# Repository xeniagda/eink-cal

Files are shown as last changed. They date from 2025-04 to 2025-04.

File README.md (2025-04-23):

# eink-cal

e-ink calendar based on the *esp32-wroom32* and the waveshare *7.3inch e-Paper HAT (F)*

## file structure

* `./bridge_pcb/`: kicad project for the PCB
* `./eink_bridge/`: esp32-idf project for the WiFi-controller for the display
* `./case.FCStd`: freecad project modelling the 3d-printable chassis for the project
* `./cal_render/`: python code to render the calendar

## needed files

the file `./eink_bridge/main/wifi_creds.h` should be filled in with the following

```c

#ifndef wifi_creds_h_INCLUDED
#define wifi_creds_h_INCLUDED

#define WIFI_SSID "WIFI network SSID here"
#define WIFI_PASSWORD "WIFI network password"
static const char *REMOTE_IP = "IP of computer running cal_render";
static const int REMOTE_PORT = port of the above;

#endif // wifi_creds_h_INCLUDED
```

the file `./cal_render/secrets.toml` contains all calendars to be shown

```toml
[[calendar]]
# hemma
is_caldav = true # true for caldav, false for ical/http
username = "caldav username"
password = "caldav password"
url = "caldav URL"
color1 = "primary color" # one of BLACK, WHITE, BLUE, ORANGE, GREEN, RED, PURPLE
color2 = "secondary color"
```

## credits

font packaged and used is [ultlf](https://github.com/ultlang/ultlf) by emma ultlang. all parts of `./cal_render/ultlf` are re-released under the same SIL open font license.

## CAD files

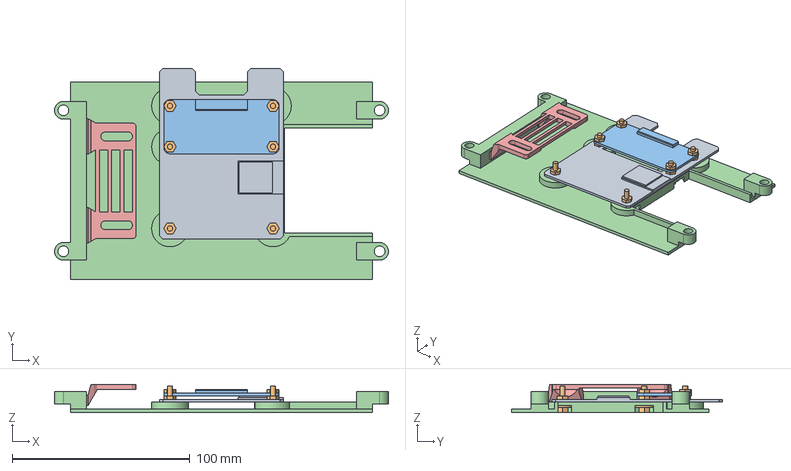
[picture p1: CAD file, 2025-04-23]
case.FCStd
188.0 x 118.7 x 16.0 mm
Bridge
Screws
Daughter001
Inner
Hanger

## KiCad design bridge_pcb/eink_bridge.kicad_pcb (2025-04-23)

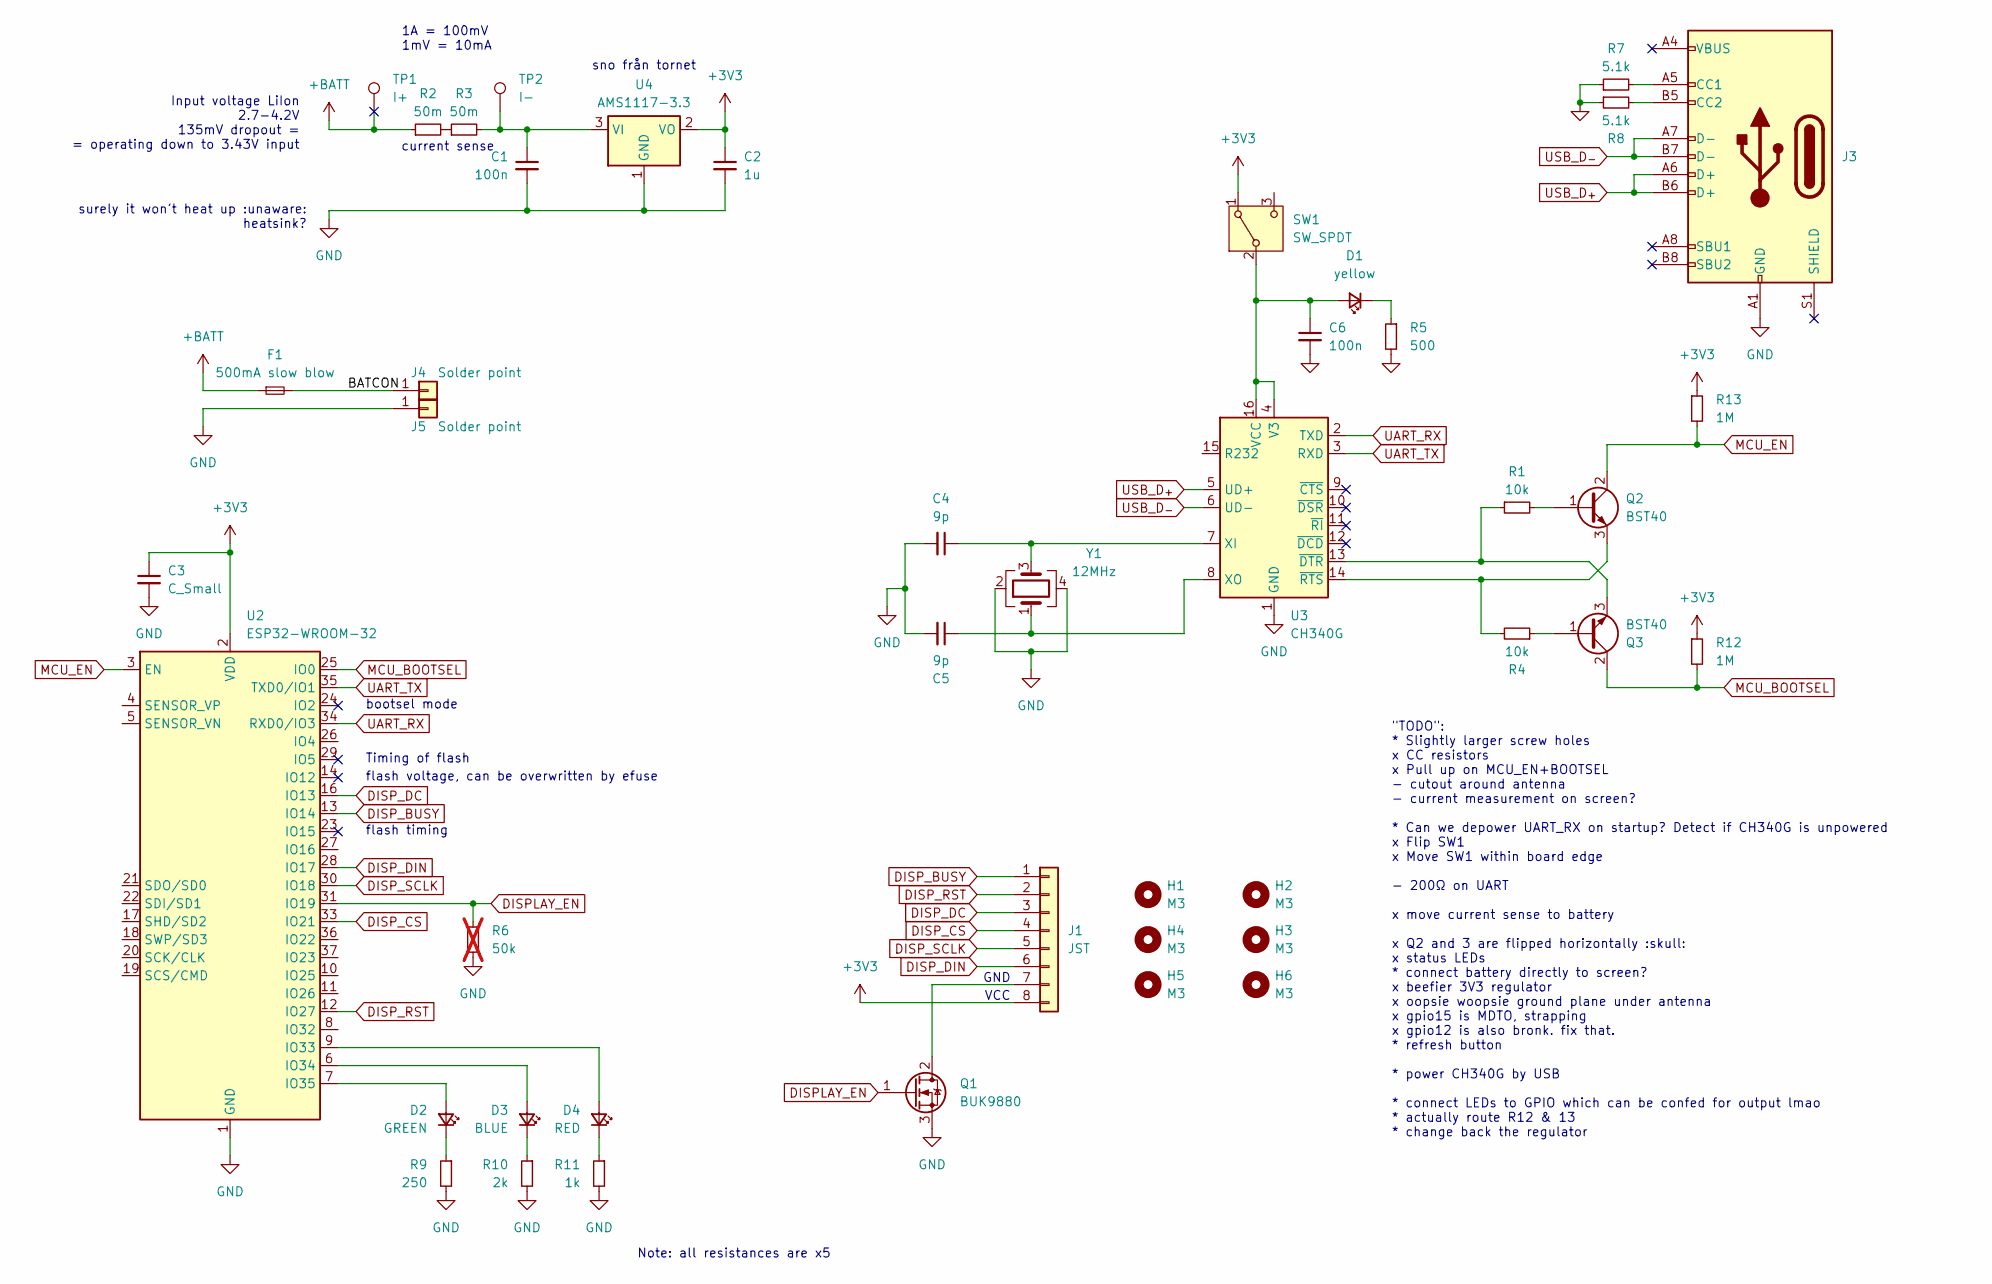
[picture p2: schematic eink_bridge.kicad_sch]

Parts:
C1, C6: 100n; C_0603_1608Metric_Pad1.08x0.95mm_HandSolder
C2: 1u; C_0603_1608Metric_Pad1.08x0.95mm_HandSolder
C3: C_Small; C_0603_1608Metric_Pad1.08x0.95mm_HandSolder
C4, C5: 9p; C_0603_1608Metric_Pad1.08x0.95mm_HandSolder
D1: yellow; D_0603_1608Metric_Pad1.05x0.95mm_HandSolder
D2: GREEN; LED_0603_1608Metric_Pad1.05x0.95mm_HandSolder
D3: BLUE; LED_0603_1608Metric_Pad1.05x0.95mm_HandSolder
D4: RED; LED_0603_1608Metric_Pad1.05x0.95mm_HandSolder
F1: 500mA slow blow; Fuseholder_Cylinder-5x20mm_Schurter_OGN-SMD_Horizontal_Open
H1, H2, H3, H4, H5, H6: M3; MountingHole_3.2mm_M3
J1: JST; JST_PH_B8B-PH-SM4-TB_1x08-1MP_P2.00mm_Vertical
J3: USB_C_Receptacle_USB2.0_16P; USB_C_Receptacle_GCT_USB4110
J4, J5: Solder point; TestPoint_Keystone_5019_Minature
Q1: BUK9880; SOT-223-3_TabPin2
Q2, Q3: BST40; SOT-89-3_Handsoldering
R1, R4: 10k; R_0603_1608Metric_Pad0.98x0.95mm_HandSolder
R2, R3: 50m; R_0805_2012Metric_Pad1.20x1.40mm_HandSolder
R5: 500; R_0603_1608Metric_Pad0.98x0.95mm_HandSolder
R6: 50k; R_0603_1608Metric_Pad0.98x0.95mm_HandSolder; not fitted
R7, R8: 5.1k; R_0603_1608Metric_Pad0.98x0.95mm_HandSolder
R9: 250; R_0603_1608Metric_Pad0.98x0.95mm_HandSolder
R10: 2k; R_0603_1608Metric_Pad0.98x0.95mm_HandSolder
R11: 1k; R_0603_1608Metric_Pad0.98x0.95mm_HandSolder
R12, R13: 1M
SW1: SW_SPDT; PinHeader_1x03_P2.54mm_Horizontal
TP1: I+; TestPoint_Bridge_Pitch3.81mm_Drill1.3mm
TP2: I-; TestPoint_Bridge_Pitch3.81mm_Drill1.3mm
U2: ESP32-WROOM-32
U3: CH340G; SOIC-16_3.9x9.9mm_P1.27mm
U4: AMS1117-3.3; SOT-223-3_TabPin2
Y1: 12MHz; Crystal_SMD_3225-4Pin_3.2x2.5mm_HandSoldering

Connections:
+3V3: C2.1, C3.1, J1.8, R12.1, R13.1, SW1.1 (A), U2.2 (VDD), U4.2 (VO)
+BATT: F1.1, R2.1, TP1.1
/BATCON: F1.2, J4.1
DISPLAY_EN: Q1.1 (G), R6.1, U2.31 (IO19)
DISP_BUSY: J1.1, U2.13 (IO14)
DISP_CS: J1.4, U2.33 (IO21)
DISP_DC: J1.3, U2.16 (IO13)
DISP_DIN: J1.6, U2.28 (IO17)
DISP_RST: J1.2, U2.12 (IO27)
DISP_SCLK: J1.5, U2.30 (IO18)
GND: C1.2, C2.2, C3.2, C4.2, C5.2, C6.2, J3.A1 (GND), J3.A12 (GND), J3.B1 (GND), J3.B12 (GND), J5.1, Q1.3 (S), R5.2, R6.2, R7.1, R8.1, R9.2, R10.2, R11.2, U2.1 (GND), U2.15 (GND), U2.38 (GND), U2.39 (GND), U3.1 (GND), U4.1 (GND), Y1.2, Y1.4
MCU_BOOTSEL: Q3.2 (C), R12.2, U2.25 (IO0)
MCU_EN: Q2.2 (C), R13.2, U2.3 (EN)
unnamed: C6.1, D1.2 (A), SW1.2 (B), U3.4 (V3), U3.16 (VCC)
unnamed: D1.1 (K), R5.1
unnamed: D2.2 (A), U2.7 (IO35)
unnamed: D2.1 (K), R9.1
unnamed: D3.2 (A), U2.6 (IO34)
unnamed: D3.1 (K), R10.1
unnamed: D4.2 (A), U2.9 (IO33)
unnamed: D4.1 (K), R11.1
unnamed: J1.7, Q1.2 (D)
unnamed: J3.A5 (CC1), R7.2
unnamed: J3.B5 (CC2), R8.2
unnamed: Q2.1 (B), R1.2
unnamed: Q2.3 (E), R4.2, U3.14 (~RTS)
unnamed: Q3.1 (B), R4.1
unnamed: Q3.3 (E), R1.1, U3.13 (~DTR)
unnamed: R2.2, R3.1
unnamed: C4.1, U3.7 (XI), Y1.3
unnamed: C5.1, U3.8 (XO), Y1.1
unnamed: C1.1, R3.2, TP2.1, U4.3 (VI)
UART_RX: U2.34 (RXD0/IO3), U3.2 (TXD)
UART_TX: U2.35 (TXD0/IO1), U3.3 (RXD)
USB_D_{+}: J3.A6 (D+), J3.B6 (D+), U3.5 (UD+)
USB_D_{-}: J3.A7 (D-), J3.B7 (D-), U3.6 (UD-)

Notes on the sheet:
GND
1A = 100mV 1mV = 10mA
VCC
current sense
flash timing
surely it won't heat up :unaware: heatsink?
sno från tornet
bootsel mode
"TODO": * Slightly larger screw holes x CC resistors x Pull up on MCU_EN+BOOTSEL - cutout around antenna - current measurement on screen? * Can we depower UART_RX on startup? Detect if CH340G is unpowered x Flip SW1 x Move SW1 within board edge - 200Ω on UART x move current sense to battery x Q2 an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
Note: all resistances are x5
flash voltage, can be overwritten by efuse
Timing of flash
Input voltage LiIon 2.7-4.2V 135mV dropout = = operating down to 3.43V input

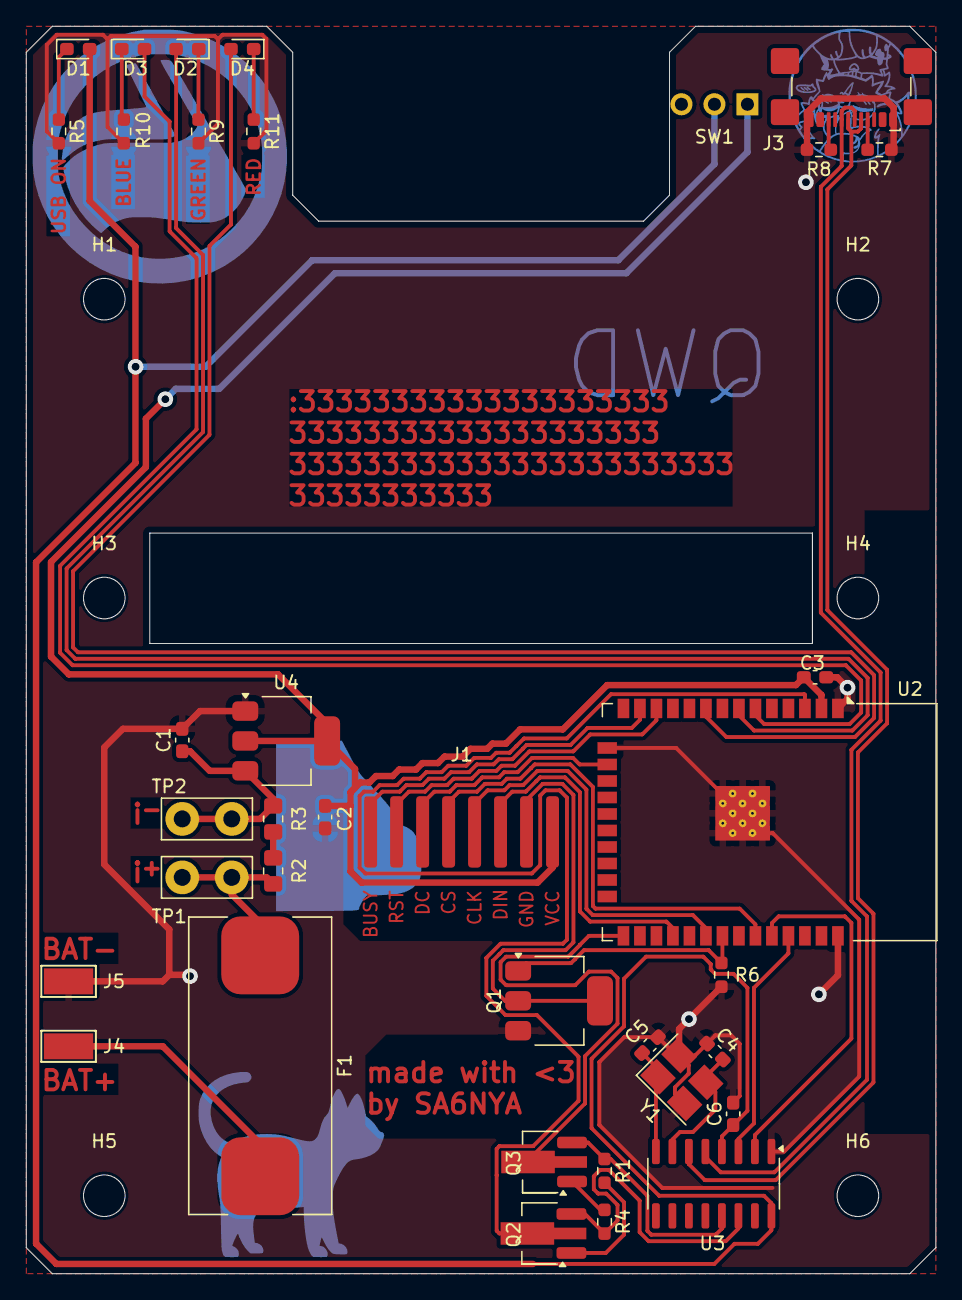
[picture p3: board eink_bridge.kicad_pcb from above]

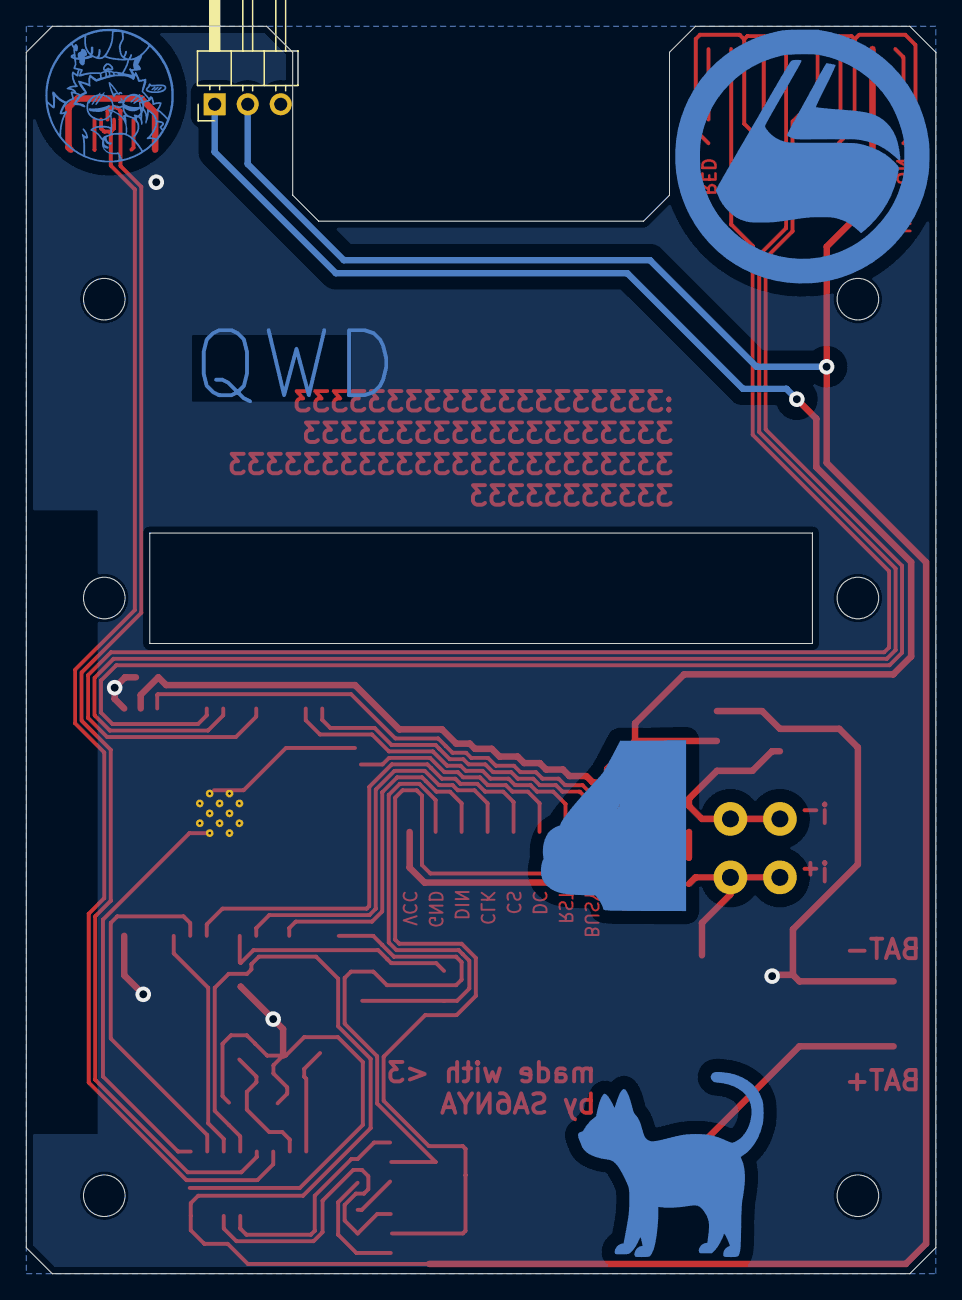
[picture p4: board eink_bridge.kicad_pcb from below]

Board: 2 copper layers, 70.0 x 96.0 mm, 44 parts (3 on the bottom side), 36 nets.

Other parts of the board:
Ref**: Val**; t42
Ref**#2: Val**; furry-antifa-20mm

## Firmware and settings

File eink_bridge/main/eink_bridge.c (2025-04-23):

#include <stdio.h>
#include <math.h>

#include "esp_err.h"
#include "esp_log.h"
#include "esp_event.h"
#include "esp_random.h"
#include "esp_sleep.h"
#include "driver/gpio.h"

#include "esp_netif.h"
#include "freertos/idf_additions.h"
#include "lwip/inet.h"
#include "nvs_flash.h"

#include "lwip/sockets.h"

#include "led.h"
#include "portmacro.h"
#include "stdint.h"
#include "wifi.h"
#include "wifi_creds.h"
#include "eink_display.h"

static const char *TAG = "eink_bridge";

static const uint64_t SLEEP_TIME_US = 4 * 60 * 60 * 1000000ull; // every 4 hours
static const uint64_t RECONNECT_ATTEMPTS = 5;
static const uint64_t RECONNECT_TIME_MS = 3000;

esp_err_t send_exact(int fd, char *buf, size_t nbytes) {
    while (nbytes > 0) {
        int written = send(fd, buf, nbytes, 0);
        if (written < 0) {
            ESP_LOGE(TAG, "Failed to send: %d", errno);
            return ESP_FAIL;
        }
        nbytes -= written;
        buf += written;
    }
    return ESP_OK;
}

esp_err_t recv_exact(int fd, char *buf, size_t nbytes) {
    while (nbytes > 0) {
        ESP_LOGD("recv_exact", "recving...");
        int recvd = recv(fd, buf, nbytes, 0);
        ESP_LOGD("recv_exact", "got %d bytes", recvd);
        if (recvd < 0) {
            ESP_LOGE(TAG, "Failed to recv: %d", errno);
            return ESP_FAIL;
        }
        if (recvd == 0) {
            ESP_LOGE(TAG, "Connection closed");
            return ESP_FAIL;
        }
        nbytes -= recvd;
        buf += recvd;
    }
    return ESP_OK;
}

float gauss() {
    #define clt_count 10
    float n = 0.;
    for (int i = 0; i < clt_count; i++) {
        // variance 1/12
        float ni = ((float) rand() / (float)RAND_MAX) - 0.5;
        n += ni;
    }
    // n has total variance clt_count/12
    return n / sqrtf(clt_count/12.0);

}

esp_err_t display_fill_pattern() {
    ESP_LOGI(TAG, "Filling display with pattern");

    //color colors = //{ COLOR_BLACK, COLOR_BLUE, COLOR_ORANGE, COLOR_GREEN, COLOR_RED, COLOR_WHITE, COLOR_YELLOW };
    color colors[6] = { COLOR_BLUE, COLOR_GREEN, COLOR_RED, COLOR_ORANGE, COLOR_YELLOW, COLOR_WHITE };

    const int N_NODES = 40;
    typedef struct {
        float x, y;
        color col1;
        color col2;
    } node;

    node nodes[N_NODES];
    for (int i = 0; i < N_NODES; i++) {
        color col1 = colors[esp_random() % 6];
        color col2 = esp_random() % 2 == 0 ? col1 : colors[rand() % 6];

        nodes[i] = (node) {
            .x = (float) esp_random() / (float)UINT32_MAX * DISPLAY_WIDTH,
            .y = (float) esp_random() / (float)UINT32_MAX * DISPLAY_HEIGHT,
            .col1 = col1,
            .col2 = col2,
        };
    }

    display_begin_frame();

    int block_size = 10000;
    color *current_block = malloc(block_size * sizeof(color));
    int n = 0;

    for (int y = 0; y < DISPLAY_HEIGHT; y++) {
        for (int x = 0; x < DISPLAY_WIDTH; x++) {
            // color col;
            // float xx = x - DISPLAY_WIDTH/2.0;
            // float yy = y - DISPLAY_HEIGHT/2.0;

            // float pi = 3.14159265359;
            // float theta = ((atan2(yy, xx) + pi) / (2 * pi) * 360);
            // theta += gauss() * 360.0/7.0 * 0.3;

            // int ii = (int) (theta * 7 / 360);
            // col = colors[(ii < 0) ? 0 : (ii >= 6) ? 6 : ii];

            float min_dist = INFINITY;
            node *closest;
            node *second_closest;

            for (int i = 0; i < N_NODES; i++) {
                node n = nodes[i];
                float dist = sqrtf((x - n.x) * (x - n.x) + (y - n.y) * (y - n.y));
                if (dist < min_dist) {
                    second_closest = closest;
                    closest = &nodes[i];
                    min_dist = dist;
                }
            }
            // midpoint (lies on line)
            float mx = (closest->x + second_closest->x)/2;
            float my = (closest->y + second_closest->y)/2;

            // vector from p2 to p1 (perpendicular to line)
            float dx = second_closest->x - closest->x;
            float dy = second_closest->y - closest->y;
            // normalize
            float d = sqrtf(dx*dx + dy*dy);
            dx /= d; dy /= d;

            // vector from midpoint to this point
            float ex = x - mx;
            float ey = y - my;

            // project e onto d to get distance from this point to line
            float dist = ex * dx + ey * dy;

            color col = (x + y) % 2 == 0 ? closest->col1 : closest->col2;

            float width_here = 2;// + (float) esp_random() / (float) UINT32_MAX;
            if (dist > -width_here / 2 && dist < width_here / 2) {
                col = COLOR_BLACK;
            }

            current_block[n++] = col;
            if (n == block_size) {
                display_send_data(current_block, n);
                n = 0;
            }
        }
    }
    display_send_data(current_block, n);

    free(current_block);

    ESP_LOGI(TAG, "Sent all data");

    display_end_frame();

    return ESP_OK;
}

void go_to_sleep() {
    ESP_LOGI(TAG, "Entering deep sleep for %" PRIu64 ".%06" PRIu64 " s. Bye!", SLEEP_TIME_US / 1000000, SLEEP_TIME_US % 1000000);

    ESP_LOGV(TAG, "Setting timer");
    esp_sleep_enable_timer_wakeup(SLEEP_TIME_US);

    ESP_LOGV(TAG, "Disabling UART");
    const int UART_TX = 1;
    gpio_config_t cfg = {
        .pin_bit_mask = (uint64_t) 1 << UART_TX,
        .mode = GPIO_MODE_DISABLE,
        .pull_up_en = GPIO_PULLUP_DISABLE,
        .pull_down_en = GPIO_PULLDOWN_DISABLE,
        .intr_type = GPIO_INTR_DISABLE,
    };
    ESP_ERROR_CHECK(gpio_config(&cfg));
    // no one can hear us say goodbye :(

    esp_deep_sleep_start();
}

void show_failure() {
    ESP_LOGE(TAG, "FAILURE. Displaying fail pattern");
    led_set(LED_COLOR_RED);
    display_fill_pattern();
    display_turn_off();
    led_deinit();
    go_to_sleep();
}

// led indicator:
// blue: initialized, configuring display
// yellow: connecting to wifi
// blue: connecting to socket
// purple: transferring data
// white: waiting for refresh
// green: done

void app_main(void)
{
    ESP_LOGI(TAG, "initializing");
    ESP_ERROR_CHECK(nvs_flash_init()); // why is this needed?
    ESP_ERROR_CHECK(esp_netif_init()); // to subscribe to wifi events
    ESP_ERROR_CHECK(esp_event_loop_create_default());
    ESP_ERROR_CHECK(led_init());

    led_set(LED_COLOR_WHITE);

    ESP_LOGI(TAG, "configuring display");
    display_config display_cfg = {
        // rev. 1
        // .gpio_spi_mosi = 17,
        // .gpio_spi_clk = 16,
        // .gpio_spi_cs = 15,
        // .gpio_spi_dc = 14,
        // .gpio_reset = 13,
        // .gpio_busy = 12,

        // .gpio_en = 19,

        // rev. 2
        .gpio_spi_mosi = 17,
        .gpio_spi_clk = 18,
        .gpio_spi_cs = 21,
        .gpio_spi_dc = 13,
        .gpio_reset = 27,
        .gpio_busy = 14,

        .gpio_en = 19,
    };
    ESP_ERROR_CHECK(display_initialize(display_cfg));

    led_set(LED_COLOR_YELLOW);

    ESP_LOGI(TAG, "connecting to wifi");

    start_wifi_cfg wificfg = {
        .hostname = "eink_bridge",
        .ssid = WIFI_SSID,
        .password = WIFI_PASSWORD,
    };
    start_wifi_result wifires;
    if (wifi_connect(&wificfg, &wifires) != ESP_OK) {
        ESP_LOGE(TAG, "Failed to connect to wifi");
        show_failure();
    }

    char ipbuf[20];
    esp_ip4addr_ntoa(&wifires.addr, ipbuf, sizeof ipbuf);
    ESP_LOGI(TAG, "Got DHCP IP: %s", ipbuf);

    led_set(LED_COLOR_GREEN);

    // set up socket
    struct sockaddr addr;
    struct sockaddr_in *addr_in = (struct sockaddr_in *) &addr; // is this UB?
    addr_in->sin_family = AF_INET;
    addr_in->sin_port = htons(REMOTE_PORT);
    addr_in->sin_addr.s_addr = esp_ip4addr_aton(REMOTE_IP);

    int socket_fd = -1;
    for (int i = 1; i <= RECONNECT_ATTEMPTS; i++) {
        ESP_LOGI(TAG, "Connect attempt %i", i);
        socket_fd = socket(AF_INET, SOCK_STREAM, IPPROTO_IP);
        if (socket_fd < 0) {
            ESP_LOGE(TAG, "Unable to create socket: errno %d", errno);
            show_failure();
        }
        ESP_LOGI(TAG, "Socket created. Connecting to IP %s", REMOTE_IP);
        if (connect(socket_fd, &addr, sizeof addr) < 0) {
            ESP_LOGE(TAG, "Unable to bind to socket: errno %d", errno);
            if (i == RECONNECT_ATTEMPTS) {
                ESP_LOGE(TAG, "Giving up connecting. Drawing pattern and quitting");
                show_failure();
            }
            vTaskDelay(RECONNECT_TIME_MS / portTICK_PERIOD_MS);
            close(socket_fd);
        } else {
            break;
        }
    }
    ESP_LOGI(TAG, "Connected. Sending handshake");

    ESP_ERROR_CHECK(send_exact(socket_fd, "hii^_^", 6));

    ESP_LOGI(TAG, "Receiving handshake");
    char buf[5];
    ESP_ERROR_CHECK(recv_exact(socket_fd, buf, 5));
    if (strncmp(buf, "hewwo", 5) != 0) {
        esp_system_abort("Incorrect handshake!");
        show_failure();
    }
    ESP_LOGI(TAG, "Hand shaken");

    led_set(LED_COLOR_TEAL);

    #define TRANSACTION_SIZE (800 / 2 * 20)
    color *cols = malloc(TRANSACTION_SIZE);
    display_begin_frame();
    ESP_LOGI(TAG, "Streaming data to screen");
    for (int i = 0; i < DISPLAY_HEIGHT * DISPLAY_WIDTH; i += TRANSACTION_SIZE) {
        ESP_ERROR_CHECK(recv_exact(socket_fd, (char*) cols, TRANSACTION_SIZE));
        display_send_data(cols, TRANSACTION_SIZE);
    }
    ESP_LOGI(TAG, "Closing socket");
    close(socket_fd);
    ESP_LOGI(TAG, "Done. Refreshing screen");
    // led_set(LED_COLOR_WHITE);
    display_end_frame();
    free(cols);

    ESP_LOGI(TAG, "Unpowering screen");
    display_turn_off();
    led_deinit();

    go_to_sleep();
}

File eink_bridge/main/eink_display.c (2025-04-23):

#include <stdio.h>

#include "esp_log.h"
#include "esp_err.h"
#include "freertos/FreeRTOS.h"
#include "freertos/task.h"
#include "driver/gpio.h"
#include "driver/spi_common.h"
#include "driver/spi_master.h"
#include "portmacro.h"

#include "eink_display.h"

static const char *TAG = "eink_display";
const int DISPLAY_WIDTH = 800;
const int DISPLAY_HEIGHT = 480;

esp_err_t color_validate(color c) {
    if (c < COLOR_BLACK || c > COLOR_ORANGE) {
        return ESP_FAIL;
    }
    return ESP_OK;
}

display_config active_display_cfg;
spi_device_handle_t spi_handle;

#define USER_DC_CMD ((void*) 0xCD)
#define USER_DC_DATA ((void*) 0xDA)


// NOTE: data must point to memory allocated with dma caps
esp_err_t send_data(uint8_t *data, size_t ndata) {
    if (ndata > 0) {
        gpio_set_level(active_display_cfg.gpio_spi_dc, 1);
        spi_transaction_t data_transaction = {
            .cmd = 0,
            .length = 8 * ndata,
            .tx_buffer = data,
        };

        ESP_ERROR_CHECK(spi_device_transmit(spi_handle, &data_transaction));
    }
    return ESP_OK;
}

// NOTE: data must point to memory allocated with dma capability
esp_err_t send_cmd(uint8_t command, uint8_t *data, size_t ndata) {
    ESP_LOGD(TAG, "Sending command 0x%02x with %d bytes data", command, ndata);

    gpio_set_level(active_display_cfg.gpio_spi_dc, 0);
    spi_transaction_t cmd_transaction = {
        .cmd = 0,
        .length = 8,
        .tx_buffer = &command,
    };

    ESP_ERROR_CHECK(spi_device_transmit(spi_handle, &cmd_transaction));

    send_data(data, ndata);

    return ESP_OK;
}

// TODO: Maybe don't do this polling?
void wait_until_not_busy() {
    ESP_LOGV(TAG, "Waiting for display to not be busy");
    int n = 0;
    while (gpio_get_level(active_display_cfg.gpio_busy) == 0) {
        vTaskDelay(1);
        n++;
        if (n == 1) {
            ESP_LOGD(TAG, "Waiting for display to not be busy");
        }
    }
    if (n >= 1) {
        ESP_LOGD(TAG, "Display unbusy in %d ticks", n);
    } else {
        ESP_LOGV(TAG, "Display unbusy in %d ticks", n);
    }
}

void send_startup_sequence();
void refresh();

const int TRANSACTION_SIZE = 800 / 2 * 20; // 20 rows, 24 tranactions to fill screen

esp_err_t display_initialize(display_config cfg) {
    active_display_cfg = cfg;

    ESP_LOGI(TAG, "initializing gpio");
    // initialize gpio
    gpio_config_t gpio_cfg_output = {
        .pin_bit_mask = (1 << cfg.gpio_spi_clk) | (1 << cfg.gpio_spi_dc) | (1 << cfg.gpio_spi_mosi) | (1 << cfg.gpio_spi_cs) | (1 << cfg.gpio_reset) | (1 << cfg.gpio_en),
        .mode = GPIO_MODE_OUTPUT,
        .pull_up_en = GPIO_PULLUP_DISABLE,
        .pull_down_en = GPIO_PULLDOWN_DISABLE,
        .intr_type = GPIO_INTR_DISABLE,
    };

    ESP_ERROR_CHECK(gpio_config(&gpio_cfg_output));
    gpio_config_t gpio_cfg_input = {
        .pin_bit_mask = 1 << cfg.gpio_busy,
        .mode = GPIO_MODE_INPUT,
        .pull_up_en = GPIO_PULLUP_DISABLE,
        .pull_down_en = GPIO_PULLDOWN_DISABLE,
        .intr_type = GPIO_INTR_DISABLE,
    };
    ESP_ERROR_CHECK(gpio_config(&gpio_cfg_input));

    ESP_LOGI(TAG, "powering display");
    ESP_ERROR_CHECK(gpio_set_level(cfg.gpio_en, 1));

    ESP_LOGI(TAG, "gpio done. initilazing spi bus");

    spi_bus_config_t spi_cfg = {
        .mosi_io_num = cfg.gpio_spi_mosi,
        .sclk_io_num = cfg.gpio_spi_clk,
        .max_transfer_sz = TRANSACTION_SIZE,
        .isr_cpu_id = ESP_INTR_CPU_AFFINITY_AUTO,

        .flags = SPICOMMON_BUSFLAG_MASTER,

        .miso_io_num = -1,
        .quadwp_io_num = -1,
        .quadhd_io_num = -1,
    };

    ESP_ERROR_CHECK(spi_bus_initialize(
        SPI2_HOST,
        &spi_cfg,
        SPI_DMA_CH_AUTO
    ));

    ESP_LOGI(TAG, "spi bus done. initilazing spi device");
    spi_device_interface_config_t dev_cfg = {
        .command_bits = 0,
        .address_bits = 0,
        .dummy_bits = 0,
        .mode = 0,
        .clock_source = SPI_CLK_SRC_DEFAULT,
        .clock_speed_hz = 16000000,
        .spics_io_num = cfg.gpio_spi_cs,
        .queue_size = 1,
    };
    ESP_ERROR_CHECK(spi_bus_add_device(SPI2_HOST, &dev_cfg, &spi_handle));

    ESP_LOGI(TAG, "initialize done. sending reset signal");

    gpio_set_level(cfg.gpio_reset, 1);
    vTaskDelay(10 / portTICK_PERIOD_MS);
    gpio_set_level(cfg.gpio_reset, 0);
    vTaskDelay(10 / portTICK_PERIOD_MS);
    gpio_set_level(cfg.gpio_reset, 1);
    vTaskDelay(10 / portTICK_PERIOD_MS);

    wait_until_not_busy();
    ESP_LOGI(TAG, "sent reset signal. configuring display ");

    send_startup_sequence();

    ESP_LOGI(TAG, "display configured. refreshing");

    // refresh();

    ESP_LOGI(TAG, "finished.");
    return ESP_OK;
}

void send_startup_sequence() {
    // uint8_t buffer[24];
    uint8_t *buffer = heap_caps_malloc(24, MALLOC_CAP_DMA);

    // commands stolen from rpi python library
    buffer[0] = 0x49;
    buffer[1] = 0x55;
    buffer[2] = 0x20;
    buffer[3] = 0x08;
    buffer[4] = 0x09;
    buffer[5] = 0x18;
    send_cmd(0xAA, buffer, 6);

    buffer[0] = 0x3F;
    buffer[1] = 0x00;
    buffer[2] = 0x32;
    buffer[3] = 0x2A;
    buffer[4] = 0x0E;
    buffer[5] = 0x2A;
    send_cmd(0x01, buffer, 6);

    buffer[0] = 0x5F;
    buffer[1] = 0x69;
    send_cmd(0x00, buffer, 2);

    buffer[0] = 0x00;
    buffer[1] = 0x54;
    buffer[2] = 0x00;
    buffer[3] = 0x44;
    send_cmd(0x03, buffer, 4);

    buffer[0] = 0x40;
    buffer[1] = 0x1F;
    buffer[2] = 0x1F;
    buffer[3] = 0x2C;
    send_cmd(0x05, buffer, 4);

    buffer[0] = 0x6F;
    buffer[1] = 0x1F;
    buffer[2] = 0x1F;
    buffer[3] = 0x22;
    send_cmd(0x06, buffer, 4);

    buffer[0] = 0x6F;
    buffer[1] = 0x1F;
    buffer[2] = 0x1F;
    buffer[3] = 0x22;
    send_cmd(0x08, buffer, 4);

    buffer[0] = 0x00;
    buffer[1] = 0x04;
    send_cmd(0x13, buffer, 2);

    buffer[0] = 0x3C;
    send_cmd(0x30, buffer, 1);

    buffer[0] = 0x00;
    send_cmd(0x41, buffer, 1);

    // first nibble controls the border color, but also shifts the colormap?
    // 3 is default
    // second nibble seems to do nothing?
    buffer[0] = 0x3F;
    send_cmd(0x50, buffer, 1); // border color?

    buffer[0] = 0x02;
    buffer[1] = 0x00;
    send_cmd(0x60, buffer, 2);

    buffer[0] = 0x03;
    buffer[1] = 0x20;
    buffer[2] = 0x01;
    buffer[3] = 0xE0;
    send_cmd(0x61, buffer, 4);

    buffer[0] = 0x1E;
    send_cmd(0x82, buffer, 1);

    buffer[0] = 0x00;
    send_cmd(0x84, buffer, 1);

    buffer[0] = 0x00;
    send_cmd(0x86, buffer, 1);

    buffer[0] = 0x2F;
    send_cmd(0xE3, buffer, 1);

    buffer[0] = 0x00;
    send_cmd(0xE0, buffer, 1);

    buffer[0] = 0x00;
    send_cmd(0xE6, buffer, 1);

    free(buffer);
}

uint8_t *pixel_buffer;
void display_begin_frame() {
    ESP_LOGI(TAG, "beginning frame");
    send_cmd(0x10, NULL, 0);
    pixel_buffer = heap_caps_malloc(TRANSACTION_SIZE, MALLOC_CAP_DMA);
}
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
